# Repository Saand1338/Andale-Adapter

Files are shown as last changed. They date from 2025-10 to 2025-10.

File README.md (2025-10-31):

# Andale Adapter

The Andale Adapter Project is a Wii Remote–sized adapter for Wii Guitar Hero Controllers, powered by a Raspberry Pi Pico/Pico W running Santroller firmware.
This project, through the Santroller firmware, enables these controllers to function on PC/Xbox/PlayStation platforms through USB connectivity, or though Bluetooth via custom recievers also powered by a Raspberry Pi Pico W running Santroller firmware.
The circuit boards have been designed with hand assembly in mind, and requires the soldering of both through-hole components and surface mount devices (SMD). The use of SMD components makes a soldering plate recommended equipment, but sufficient pad clearence has been used to enable careful hand soldering.

---

## Repository Structure

This repository contains three main sections:

1. **Andale Adapter** - the Adapter itself, the "brains" of the project.
2. **Slim Receiver** - a compact Bluetooth receiver, designed for low height.
3. **Tiny Receiver** - a minimal volume Bluetooth receiver, designed for portability.

All three sections include:
- KiCAD project files and Gerber outputs.
- STL files for 3D printed enclosures.
- Autodesk Fusion project files for the STLs.
- Bills of Material (BOM) files in CSV format.

> **Note:** All enclosure STLs are designed for resin printing. Extensive use of overhangs makes them less ideal for FDM printing.

---

## Overview

The Andale Adapter is designed with certain optional elements. Depending on the desired configuration, builders can choose to integrate multiple additional features:

 Feature | Description |
----------|--------------|
 Bluetooth and/or USB connectivity | Supports both wireless and wired operation. |
 RGB LED support | Allows support for up to 10 RGB LEDs on customised PCBs though a USB Micro port. |
 Controller authentication support | Required for consoles that need controller verification, done so over a regular USB port. |
 AA battery power | Recommended for Bluetooth operation. Designed around NiMH rechargable batteries. |

> **Note:** For a Bluetooth setup USB Auth is not required on the adapter. It's only required for wired configuration on console systems that require it.

---

## Assembly Order

Due to the mixed component types and modular structure, the following rough build order is recommended:

1. Prepare customised components (e.g., modified headers, trimmed USB connectors).
2. Solder Surface Mount Devices (SMDs).
3. Solder USB connectors (if applicable).
4. Solder through-hole components (e.g., headers, battery terminals).
5. Solder add-in boards (Pico, Nunchuck adapter, accelerometer).
6. Final assembly into enclosures.

---

## Andale Adapter

The Andale Adapter is the primary focus of the project, and contains the most complex components.
A small internal cable can be made to route the Pico USB Micro to a USB-C breakout board, and a sample wiring diagram is included.
Due to height & space limitations, the PCBs in the adapter are 1mm thick by design.

### Adapter Components

| Component | Purpose |
|---|---|
| Mainboard | Core PCB carrying the Pico, accelerometer, and Nunchuck adapter. |
| Battery Board | Optional PCB for AA NiMH battery power and On/Off switch. |
| Connector Board | Optional PCB for controller authentication, RGB integration (with voltage boost). |
| Internal Cable | Adapting and routing the Pico USB Micro Port to a USB-C Port on the top of the case |

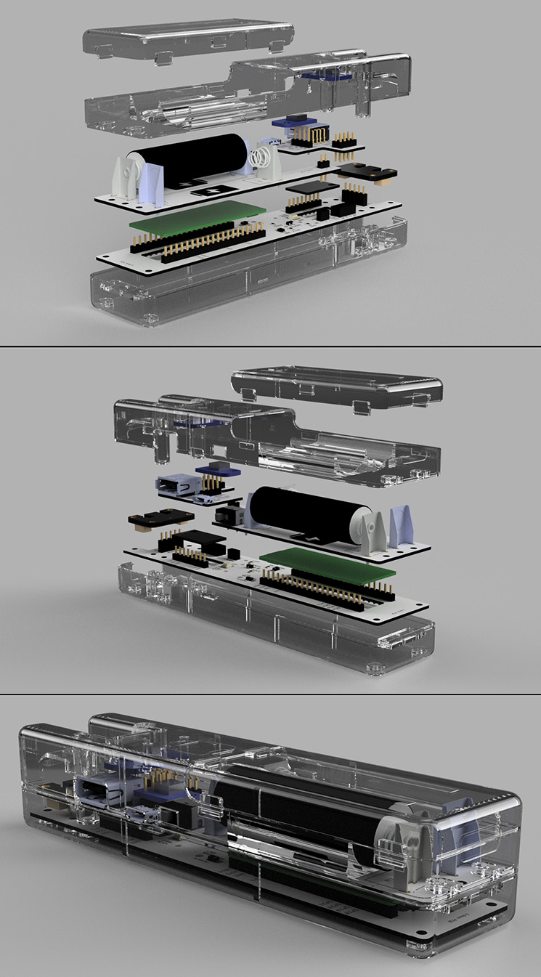
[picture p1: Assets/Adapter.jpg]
Adapter Render


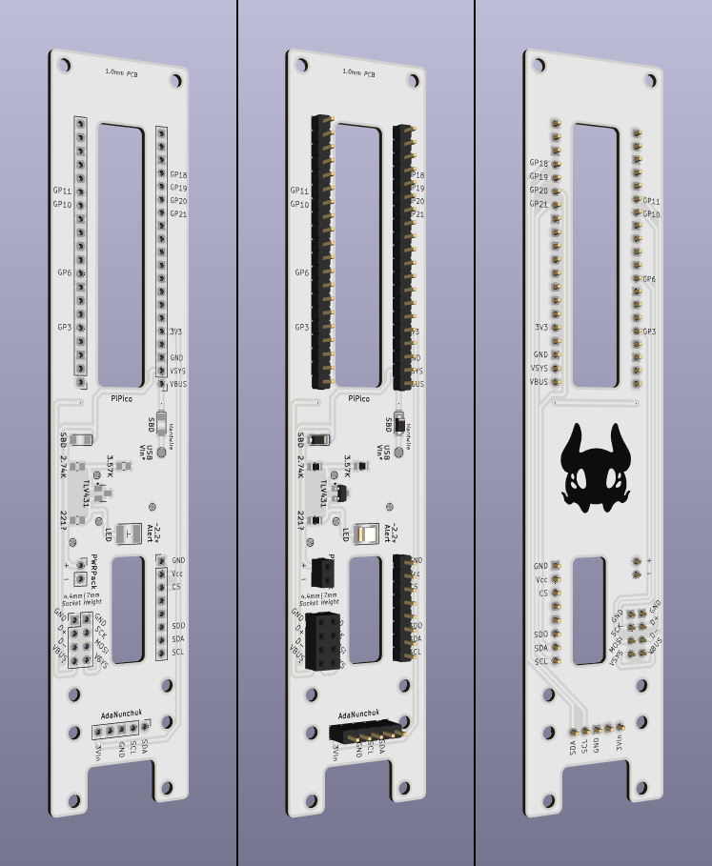
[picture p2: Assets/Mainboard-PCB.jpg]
Mainboard Render


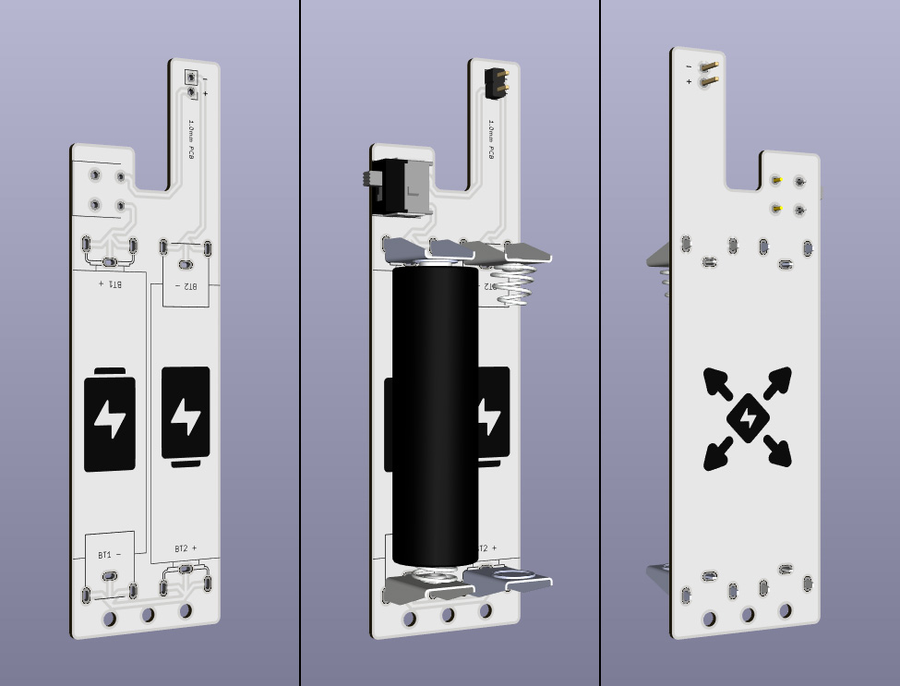
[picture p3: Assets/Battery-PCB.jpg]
Battery Board Render


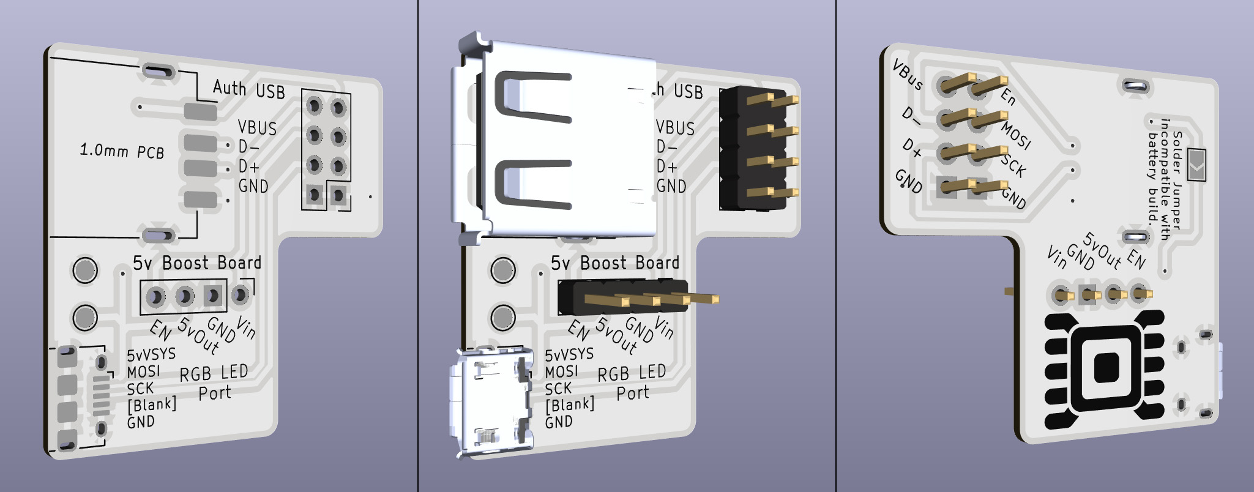
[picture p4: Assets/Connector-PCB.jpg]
Connector Board Render


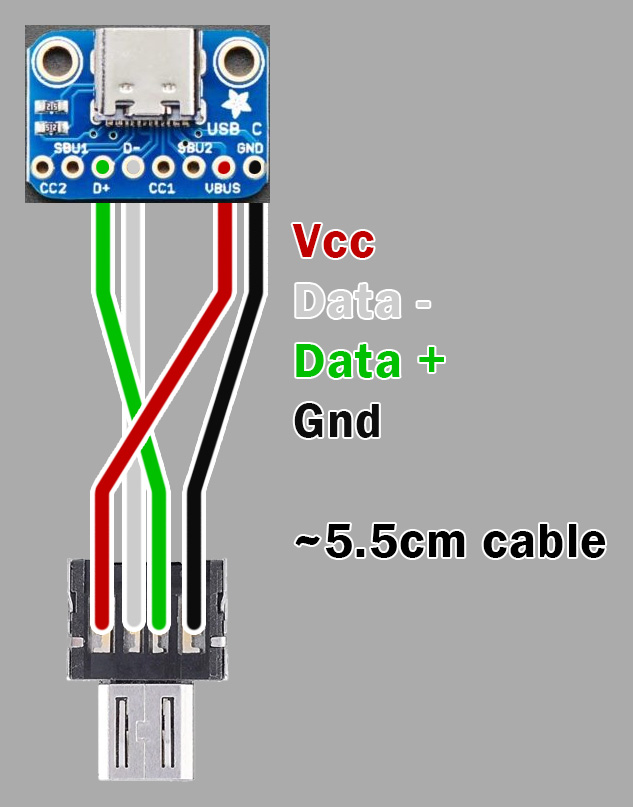
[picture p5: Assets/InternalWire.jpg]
Terrible Wiring Diagram


### Build Notes
- For Bluetooth setups, a Raspberry Pi Pico W is a requirement.
- For USB setups, either Pico or Pico W may be used.
- A USB cable or the USB-C breakout may be hardwired to the mainboard if preferred over using an internal USB Micro cable.

---

### Bill of Materials - Mainboard

| Part | Component Type | Part Code | Qty | Purpose | Notes |
|---|---|---|---|---|---|
| Pi Pico W | Commercial Product | - | 1 | Controller logic | Use Pico for wired-only builds. |
| 1x10 Low Profile Male Header | Through-hole | - | 2 | Mount for Pico W | - |
| 1x05 Male Header | Through-hole | - | 1 | Mount for Nunchuck Adapter | Requires double insulator height. |
| Adafruit Nunchuck Adapter | Commercial Product | - | 1 | Nunchuck connector integration | - |
| 1x08 Low Profile Male Header | Through-hole | - | 1 | Mount for ADXL345 | - |
| Triple Axis SEN0032 ADXL345 Board | Commercial Product | - | 1 | Accelerometer | Other ADXL345 board compatibility is uncertain. |
| 1x02 Low Profile Female Header | Through-hole | - | 1 | Powerboard plug | - |
| 1x04 Low Profile Female Header | Through-hole | - | 2 | Connector board plug | Insulator height 4 or 7 mm. |
| 20V 1A Schottky Diode | SMD (SOT-123F) | MBR120VLSFT1G | 1 | Power direction regulator | Required for battery or hardwired power. |
| LED | SMD (1208) | QBLP653-S5 | 1 | Low-voltage indicator | - |
| 1.25 V Voltage Shunt | SMD (DBZ) | TLV431DBZ | 1 | Voltage detection | Must use TL**V**431 variant. |
| 3.57 kΩ Resistor | SMD (0805) | RQ73C2A3K57BTD | 1 | Voltage divider | - |
| 2.74 kΩ Resistor | SMD (0805) | RQ73C2A2K74BTD | 1 | Voltage divider | - |
| 221 Ω Resistor | SMD (0805) | RQ73C2A221RBTD | 1 | LED current limiter | Value not optimal but functional. |
| USB Male to Micro Adapter | Commercial Product | - | 1 | Internal cable | Optional; unnecessary for a directly hardwired setup. |
| Adafruit USB-C Downstream Breakout | Commercial Product | - | 1 | External connector | - |
| Silicone Ribbon Cable (4× 28 AWG) | Commercial Product | - | 1 | Internal wiring | - |

---

### Bill of Materials - Battery Board

| Part | Component Type | Part Code | Qty | Purpose | Notes |
|---|---|---|---|---|---|
| 1x2 Male Header | Through-hole | - | 1 | Plug to mainboard | Mount upside down if using 7 mm tall header sockets. |
| On-Off Switch | Through-hole | AS11AH | 1 | Power control | - |
| AA Battery Terminal, Plate | Through-hole | Keystone 595 | 2 | Battery contact | - |
| AA Battery Terminal, Coil | Through-hole | Keystone 628 | 2 | Battery contact | - |

---

### Bill of Materials - Connector Board

| Part | Component Type | Part Code | Qty | Purpose | Notes |
|---|---|---|---|---|---|
| 1x04 Male Header | Through-hole | - | 2 | Plug to mainboard | Mount upside down if using 7 mm tall header sockets. |
| 1x04 Low Profile Male Header | Through-hole | - | 1 | Mount for TinyBoost | - |
| USB Micro Female | Through-hole | Amphenol 10118194-0001LF | 1 | RGB integration | Nonstandard use of USB port. |
| USB A Female | Through-hole | GCT USB1046 | 1 | Controller auth | Required for wired console use. |
| Adafruit MiniBoost 5V | Commercial Product | - | 1 | Voltage boost for RGB | Skip for non-battery builds. |

---

## Slim Receiver

The Slim Receiver is a Bluetooth receiver designed for consoles or PCs.
It uses a Pico W, connects directly via USB-A, and includes a secondary port for controller auth.

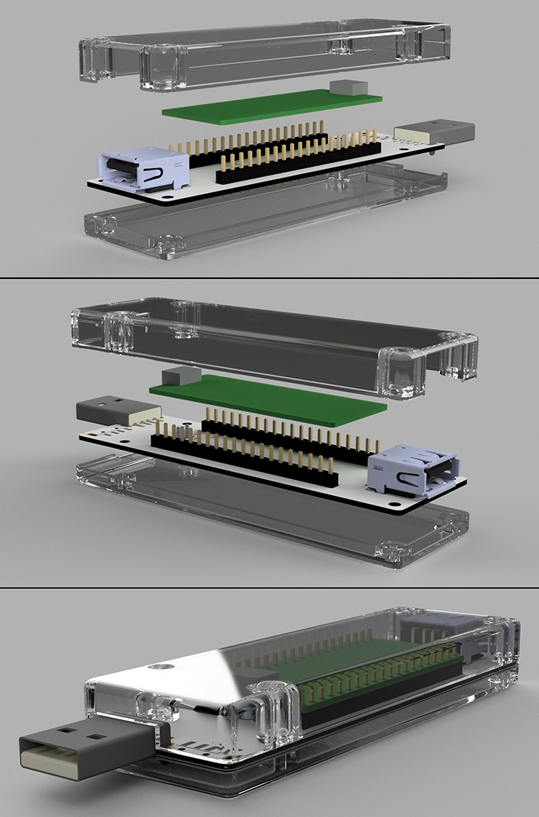
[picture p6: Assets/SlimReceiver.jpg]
Slim Receiver Render


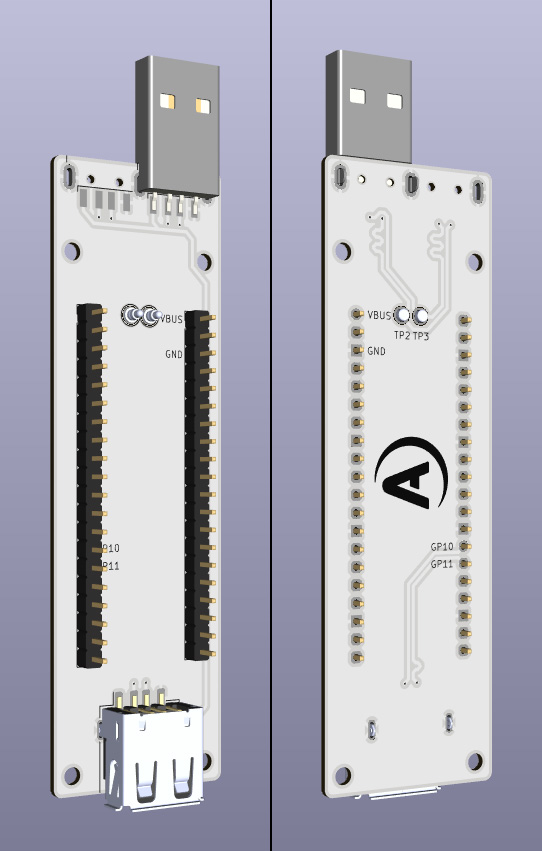
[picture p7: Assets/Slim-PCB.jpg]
Slim Board Render


### Key Characteristics
- Compact vertical height.
- Left- or right-offset USB configuration so two recievers can be used side-by-side

### Bill of Materials - Slim Receiver

| Part | Component Type | Part Code | Qty | Purpose | Notes |
|---|---|---|---|---|---|
| Pi Pico W | Commercial Product | - | 1 | Logic | Required. |
| 1x10 Low Profile Male Header | Through-hole | - | 2 | Mount for Pico W | - |
| USB A Male | Through-hole | CNCTech 1001-011-01101 | 1 | Plug for console/PC | Offset configuration possible. |
| USB A Female | Through-hole | GCT USB1046 | 1 | Auth plug | Required for consoles needing authentication. |
| 3.18 mm → 1.78 mm Pogo Pin | Through-hole | 0926-1-15-20-75-14-11-0 | 2 | Pico testpoint connection | 2.54 mm target height. |

---

## Tiny Receiver

The Tiny Receiver alternatively offers a minimal design for ease of transport. It does however have a larger vertical height and worse horizontal clearance, so fitting multiple in side-by-side USB ports may be impossible.
It mounts the Pico W directly underneath the PCB, requiring precise soldering and a fine-tipped soldering iron.

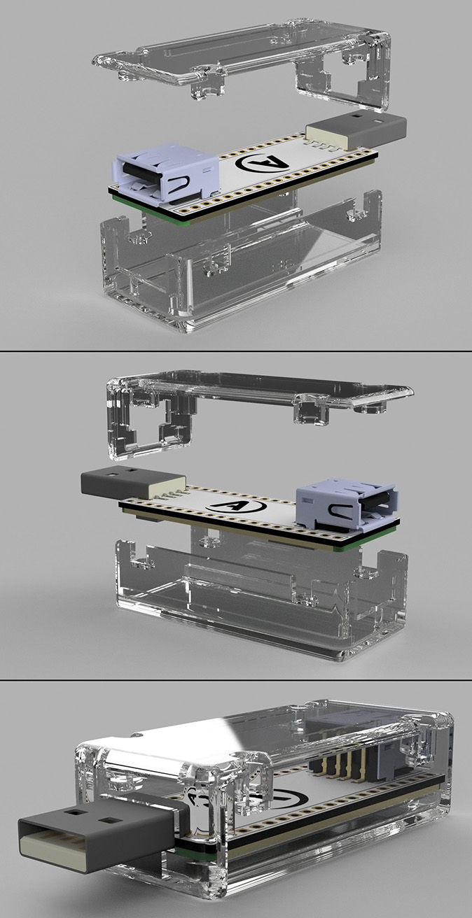
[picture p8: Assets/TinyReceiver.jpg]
Tiny Receiver Render


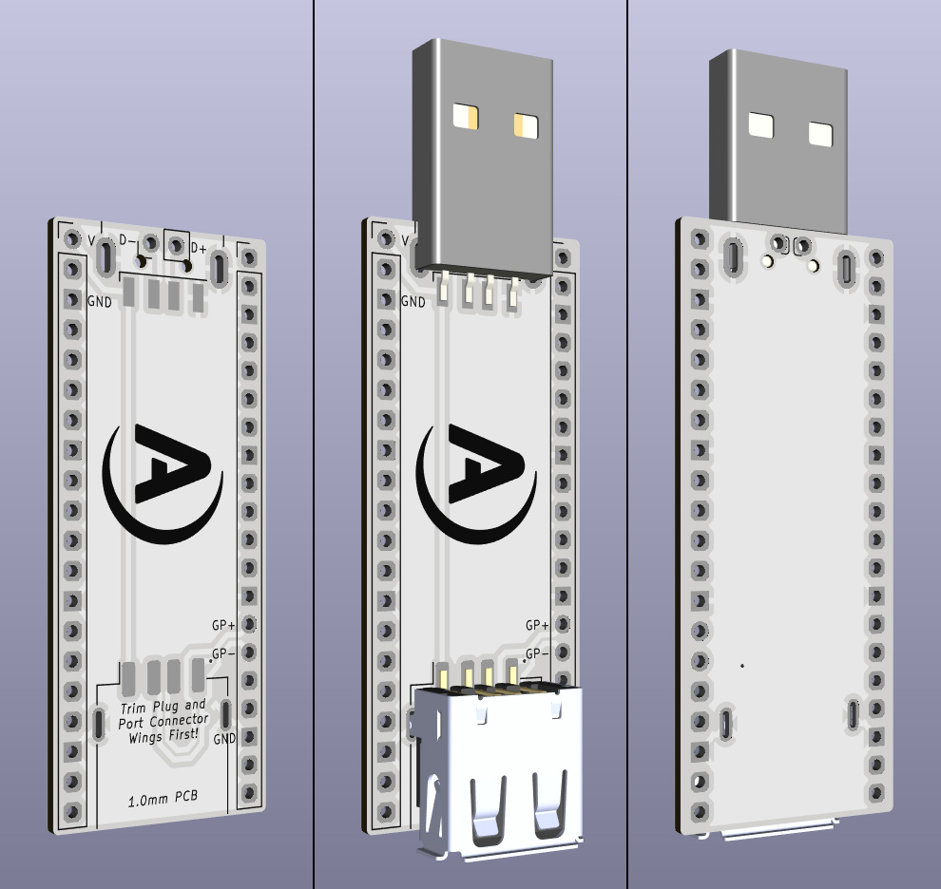
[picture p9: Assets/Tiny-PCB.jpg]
Tiny Board Render


### Build Notes
- Mount the Pico W on the underside and solder through the seven marked pads.
- Trim USB plug and port wings to fit enclosure.
- Difficult to build & repair. Not recommended.

### Bill of Materials - Tiny Receiver

| Part | Component Type | Part Code | Qty | Purpose | Notes |
|---|---|---|---|---|---|
| Pi Pico W | Commercial Product | - | 1 | Logic | Mounted underside. |
| USB A Male | Through-hole | CNCTech 1001-011-01101 | 1 | Main plug | Trim wings to < 1 mm. |
| USB A Female | Through-hole | GCT USB1046 | 1 | Auth port | Trim wings to < 1 mm. |

---

## Hardware Fasteners

A bulk pack of metric M2 machine screws is recommended.

| Section | Part | Component Type | Qty | Purpose |
|---|---|---|---|---|
| Adapter Shell | M2 Machine Screw 4 mm | Commercial Product | 3 | Mounts mainboard, power board |
| Adapter Shell | M2 Machine Screw 6 mm | Commercial Product | 4 | Mounts breakout, shell rear |
| Adapter Shell | M2 Machine Screw 8 mm | Commercial Product | 2 | Mounts shell front |
| Slim Shell | M2 Machine Screw 6 mm | Commercial Product | 4 | Holds halves together |
| Tiny Shell | M2 Machine Screw 6 mm | Commercial Product | 4 | Holds halves together |

---

## Firmware

This project uses Santroller firmware by sanjay900.
All credit for firmware functionality belongs to the original author.

For more information visit the Santroller website.

---

## Thanks

Thank you to Sanjay & the Santroller community. They were openly welcoming and provided a great deal of support and validation during the development of this project. It would not have been possible without them.

---

## Licensing

All designs, documents, and files in this repository are released under the **Creative Commons Attribution–ShareAlike (CC-BY-SA)** license.
You are free to modify, distribute, and remix, provided that proper credit is given and derivatives are shared under the same terms.

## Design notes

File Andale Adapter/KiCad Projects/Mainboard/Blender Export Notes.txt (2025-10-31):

Blender Export Notes

Using Blender to convert board WRLs to OBJ for import into Fusion 360, on my system the axies need to be set to positive z and positive y to then import in the expected planar orientation.

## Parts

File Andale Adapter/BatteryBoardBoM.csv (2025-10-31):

Part | Component Type | Part Code | Qty | Purpose | Notes
1x2 Male Header | Through-hole |  | 1 | Plug into Mainboard | For 7mm header insulator mount upside down
On-Off Switch | Through-hole | AS11AH | 1 | Power switch
AA Battery Terminal, Plate | Through-hole | 595 | 2 | Battery mount (plate)
AA Battery Terminal, Coil | Through-hole | 628 | 2 | Battery mount (coil)

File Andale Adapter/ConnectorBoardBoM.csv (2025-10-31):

Part | Component Type | Part Code | Qty | Purpose | Notes
1x04 Male Header | Through-hole |  | 2 | Plug into Mainboard | For 7mm insulator mount upside down
1x04 Low Profile Male Header | Through-hole |  | 1 | Mount for TinyBoost
USB Micro Female | Through-hole | Amphenol 10118194-0001LF | 1 | RGB integration (abuse of USB Micro)
USB A Female | Through-hole | GCT USB1046 | 1 | Controller auth (Wired)
Adafruit MiniBoost 5V | Commercial Product |  | 1 | Boost converter for RGB on battery | Optional for non-battery builds

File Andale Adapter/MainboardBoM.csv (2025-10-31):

Part | Component Type | Part Code | Qty | Purpose | Notes
Pi Pico W | Commercial Product |  | 1 | Brains | Use Pico W for Bluetooth builds
1x10 Low Profile Male Header (x2) | Through-hole |  | 2 | Mount for Pico W
1x05 Male Header | Through-hole |  | 1 | Mount for Nunchuck Adapter | Requires double insulator height; custom modification
Adafruit Nunchuck Adapter | Commercial Product |  | 1 | Nunchuck connector integration
1x08 Low Profile Male Header | Through-hole |  | 1 | Mount for ADXL345
Triple Axis SEN0032 ADXL345 Board | Commercial Product |  | 1 | Accelerometer | Other ADXL345 compatibility unverified
1x02 Low Profile Female Header | Through-hole |  | 1 | Powerboard plug
1x04 Low Profile Female Header (x2) | Through-hole |  | 2 | Connector board plug | Insulator height must be 4mm or 7mm
20V 1A Schottky Diode | SMD (SOT-123F) | MBR120VLSFT1G | 0-1 | Power direction regulator | Required for battery or hardwired power
LED | SMD (1208) | QBLP653-S5 | 1 | Low-voltage indicator
1.25 V Voltage Shunt | SMD (DBZ) | TLV431DBZ | 1 | Voltage detection | Must use TLV variant (not TL431)
3.57 kΩ Resistor | SMD (0805) | RQ73C2A3K57BTD | 1 | Voltage divider
2.74 kΩ Resistor | SMD (0805) | RQ73C2A2K74BTD | 1 | Voltage divider
221 Ω Resistor | SMD (0805) | RQ73C2A221RBTD | 1 | LED current limiter | Value arbitrary; not optimized
USB Male to USB-Micro Male adapter | Commercial Product |  | 1 | Internal cable (optional) | Unnecessary in hardwire config
Adafruit USB C Downstream Breakout | Commercial Product |  | 1 | USB-C connector breakout
Silicone Ribbon Cable, 4x 28AWG | Commercial Product |  | 1 | Internal wiring

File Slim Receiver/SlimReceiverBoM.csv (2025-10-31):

Part | Component Type | Part Code | Qty | Purpose | Notes
Pi Pico W | Commercial Product |  | 1 | Brains
1x10 Low Profile Male Header (x2) | Through-hole |  | 2 | Mount for Pico W
USB A Male | Through-hole | CNCTech 1001-011-01101 | 1 | USB stick plug | Offset left/right configs available
USB A Female | Through-hole | GCT USB1046 | 1 | Auth plug (wireless config)
3.18mm->1.78mm Pogo Pin | Through-hole | 0926-1-15-20-75-14-11-0 | 2 | Pico testpoint connectors | Target height 2.54mm (header insulator height)

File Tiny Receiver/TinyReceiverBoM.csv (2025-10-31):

Part | Component Type | Part Code | Qty | Purpose | Notes
Pi Pico W | Commercial Product |  | 1 | Brains | Mounted underside; advanced soldering required
USB A Male | Through-hole | CNCTech 1001-011-01101 | 1 | USB stick plug | Trim mounting prongs under 1mm
USB A Female | Through-hole | GCT USB1046 | 1 | Auth plug | Trim mounting prongs under 1mm

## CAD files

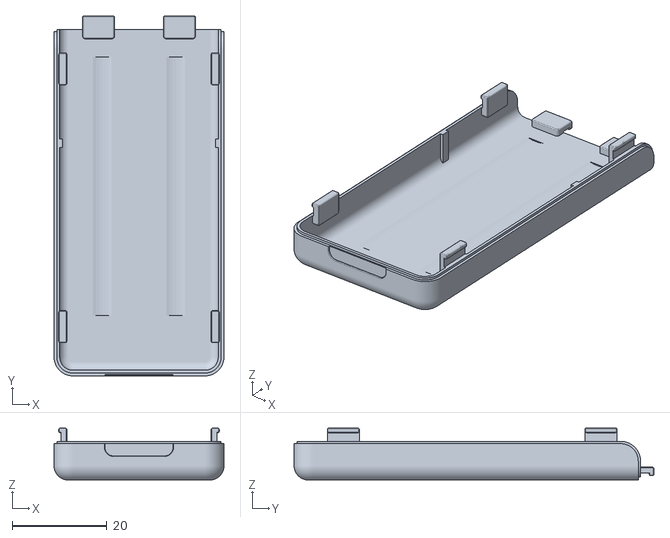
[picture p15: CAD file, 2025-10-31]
Andale Adapter/Fusion360 Project/STL Exports/AdapterShellBatteryCover.stl
35.8 x 75.8 x 10.9

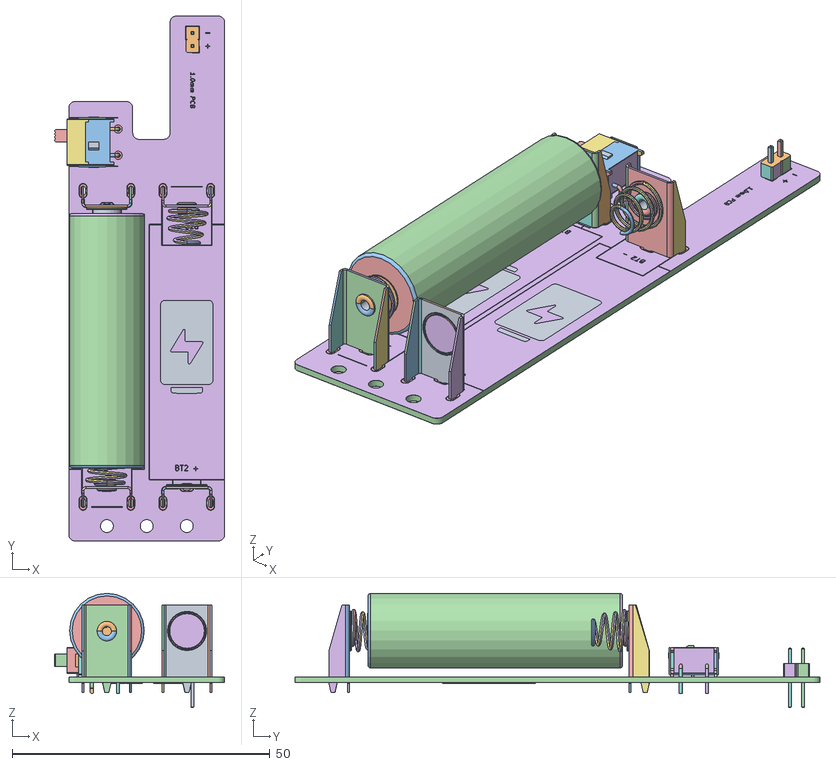
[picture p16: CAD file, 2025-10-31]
Andale Adapter/KiCad Projects/Exports/BatteryBoard.obj
33.1 x 101.9 x 22.2
SHAPE_1_IndexedFaceSet
SHAPE_2_IndexedFaceSet
SHAPE_3_IndexedFaceSet
SHAPE_4_IndexedFaceSet
SHAPE_5_IndexedFaceSet
SHAPE_6_IndexedFaceSet
SHAPE_7_IndexedFaceSet
SHAPE_8_IndexedFaceSet
SHAPE_9_IndexedFaceSet
SHAPE_10_IndexedFaceSet
SHAPE_11_IndexedFaceSet
SHAPE_12_IndexedFaceSet
SHAPE_13_IndexedFaceSet
SHAPE_14_IndexedFaceSet
SHAPE_15_IndexedFaceSet
SHAPE_16_IndexedFaceSet
SHAPE_17_IndexedFaceSet
SHAPE_18_IndexedFaceSet
SHAPE_19_IndexedFaceSet
SHAPE_20_IndexedFaceSet
SHAPE_21_IndexedFaceSet
SHAPE_22_IndexedFaceSet
SHAPE_23_IndexedFaceSet
SHAPE_24_IndexedFaceSet
SHAPE_25_IndexedFaceSet
SHAPE_26_IndexedFaceSet
SHAPE_27_IndexedFaceSet
SHAPE_28_IndexedFaceSet
SHAPE_29_IndexedFaceSet
SHAPE_30_IndexedFaceSet
SHAPE_31_IndexedFaceSet
SHAPE_32_IndexedFaceSet
SHAPE_33_IndexedFaceSet
SHAPE_34_IndexedFaceSet
SHAPE_35_IndexedFaceSet
SHAPE_36_IndexedFaceSet
SHAPE_37_IndexedFaceSet
SHAPE_38_IndexedFaceSet
SHAPE_39_IndexedFaceSet
SHAPE_40_IndexedFaceSet
SHAPE_41_IndexedFaceSet
SHAPE_42_IndexedFaceSet
SHAPE_43_IndexedFaceSet
SHAPE_44_IndexedFaceSet
SHAPE_45_IndexedFaceSet
SHAPE_46_IndexedFaceSet
SHAPE_47_IndexedFaceSet
SHAPE_48_IndexedFaceSet
SHAPE_49_IndexedFaceSet
SHAPE_50_IndexedFaceSet
SHAPE_51_IndexedFaceSet
SHAPE_52_IndexedFaceSet
SHAPE_53_IndexedFaceSet
SHAPE_54_IndexedFaceSet
SHAPE_55_IndexedFaceSet
SHAPE_56_IndexedFaceSet
SHAPE_1_IndexedFaceSet.001
SHAPE_2_IndexedFaceSet.001
SHAPE_3_IndexedFaceSet.001
SHAPE_4_IndexedFaceSet.001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

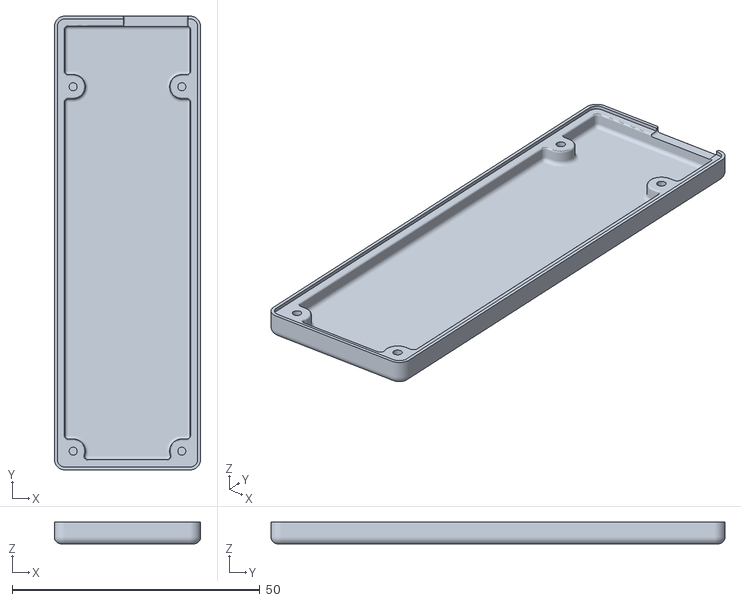
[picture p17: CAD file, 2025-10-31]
Slim Receiver/Fusion360 Project/STL Exports/SlimRight_Bottom.stl
29.5 x 91.6 x 4.41

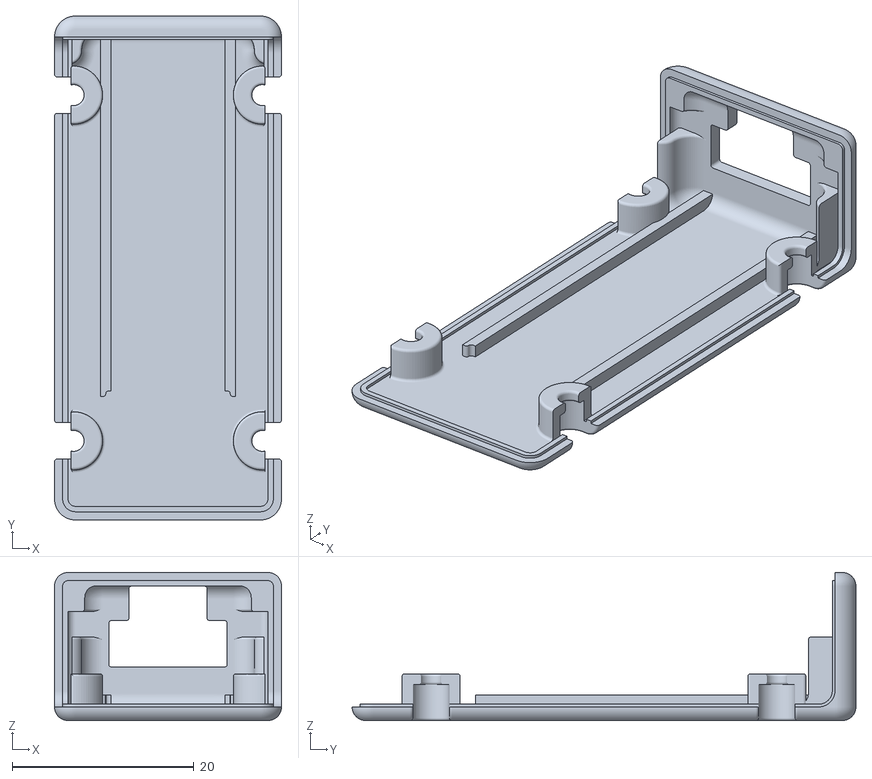
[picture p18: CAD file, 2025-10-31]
Tiny Receiver/Fusion360 Project/STL Exports/Shell_Top.stl
25.0 x 55.5 x 16.3

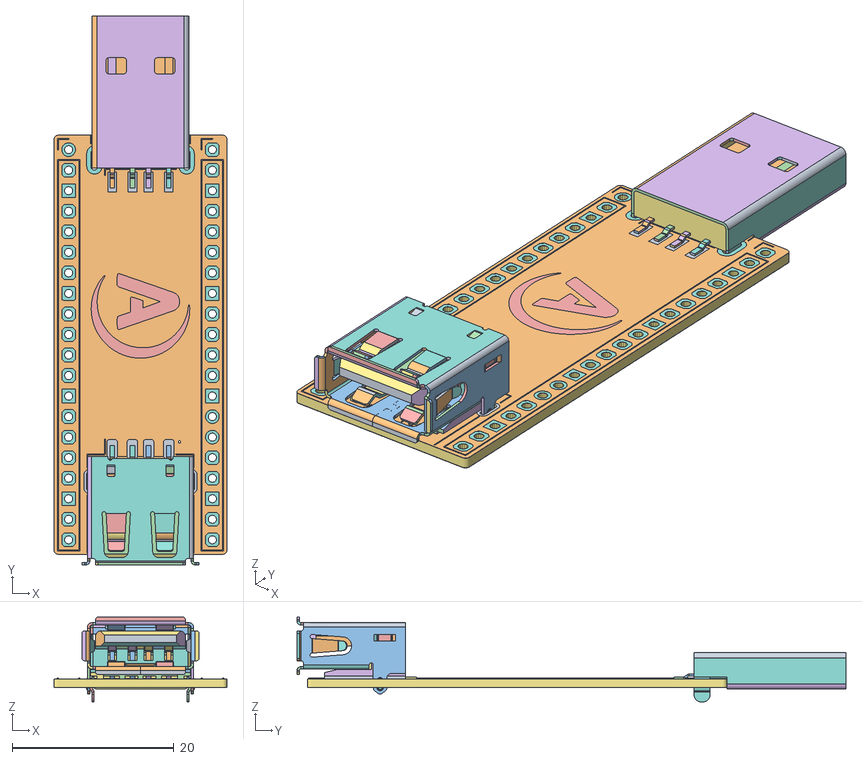
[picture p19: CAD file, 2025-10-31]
Tiny Receiver/KiCad Project/Exports/TinyReceiver.obj
21.4 x 67.9 x 10.5
SHAPE_1_IndexedFaceSet
SHAPE_2_IndexedFaceSet
SHAPE_3_IndexedFaceSet
SHAPE_4_IndexedFaceSet
SHAPE_5_IndexedFaceSet
SHAPE_6_IndexedFaceSet
SHAPE_7_IndexedFaceSet
SHAPE_8_IndexedFaceSet
SHAPE_9_IndexedFaceSet
SHAPE_10_IndexedFaceSet
SHAPE_11_IndexedFaceSet
SHAPE_12_IndexedFaceSet
SHAPE_13_IndexedFaceSet
SHAPE_14_IndexedFaceSet
SHAPE_15_IndexedFaceSet
SHAPE_16_IndexedFaceSet
SHAPE_17_IndexedFaceSet
SHAPE_18_IndexedFaceSet
SHAPE_19_IndexedFaceSet
SHAPE_20_IndexedFaceSet
SHAPE_21_IndexedFaceSet
SHAPE_22_IndexedFaceSet
SHAPE_23_IndexedFaceSet
SHAPE_24_IndexedFaceSet
SHAPE_25_IndexedFaceSet
SHAPE_26_IndexedFaceSet
SHAPE_27_IndexedFaceSet
SHAPE_28_IndexedFaceSet
SHAPE_29_IndexedFaceSet
SHAPE_30_IndexedFaceSet
SHAPE_31_IndexedFaceSet
SHAPE_32_IndexedFaceSet
SHAPE_33_IndexedFaceSet
SHAPE_34_IndexedFaceSet
SHAPE_35_IndexedFaceSet
SHAPE_36_IndexedFaceSet
SHAPE_37_IndexedFaceSet
SHAPE_38_IndexedFaceSet
SHAPE_39_IndexedFaceSet
SHAPE_40_IndexedFaceSet
SHAPE_41_IndexedFaceSet
SHAPE_42_IndexedFaceSet
SHAPE_43_IndexedFaceSet
SHAPE_44_IndexedFaceSet
SHAPE_45_IndexedFaceSet
SHAPE_46_IndexedFaceSet
SHAPE_47_IndexedFaceSet
SHAPE_48_IndexedFaceSet
SHAPE_49_IndexedFaceSet
SHAPE_50_IndexedFaceSet
SHAPE_51_IndexedFaceSet
SHAPE_52_IndexedFaceSet
SHAPE_53_IndexedFaceSet
SHAPE_54_IndexedFaceSet
SHAPE_55_IndexedFaceSet
SHAPE_56_IndexedFaceSet
SHAPE_57_IndexedFaceSet
SHAPE_58_IndexedFaceSet
SHAPE_59_IndexedFaceSet
SHAPE_60_IndexedFaceSet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

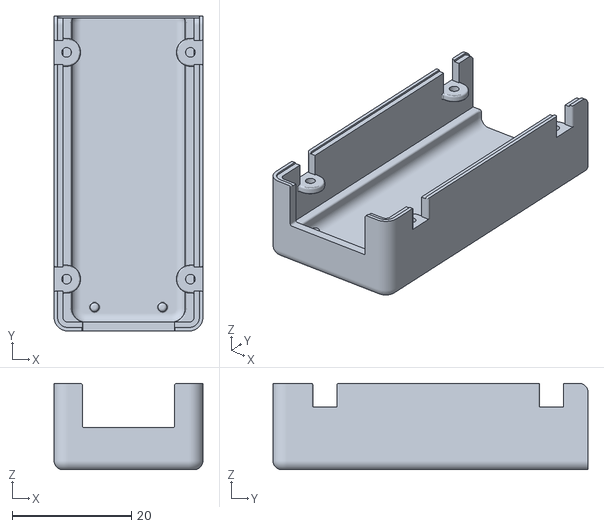
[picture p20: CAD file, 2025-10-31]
Tiny Receiver/Fusion360 Project/STL Exports/Shell_Bottom.stl
25.0 x 52.9 x 14.5

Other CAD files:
Slim Receiver/Fusion360 Project/STL Exports/SlimLeft_Bottom.stl
Andale Adapter/Fusion360 Project/AndaleAdapter.f3d
Slim Receiver/Fusion360 Project/SlimReceiver.f3d
Tiny Receiver/Fusion360 Project/TinyReceiver.f3d

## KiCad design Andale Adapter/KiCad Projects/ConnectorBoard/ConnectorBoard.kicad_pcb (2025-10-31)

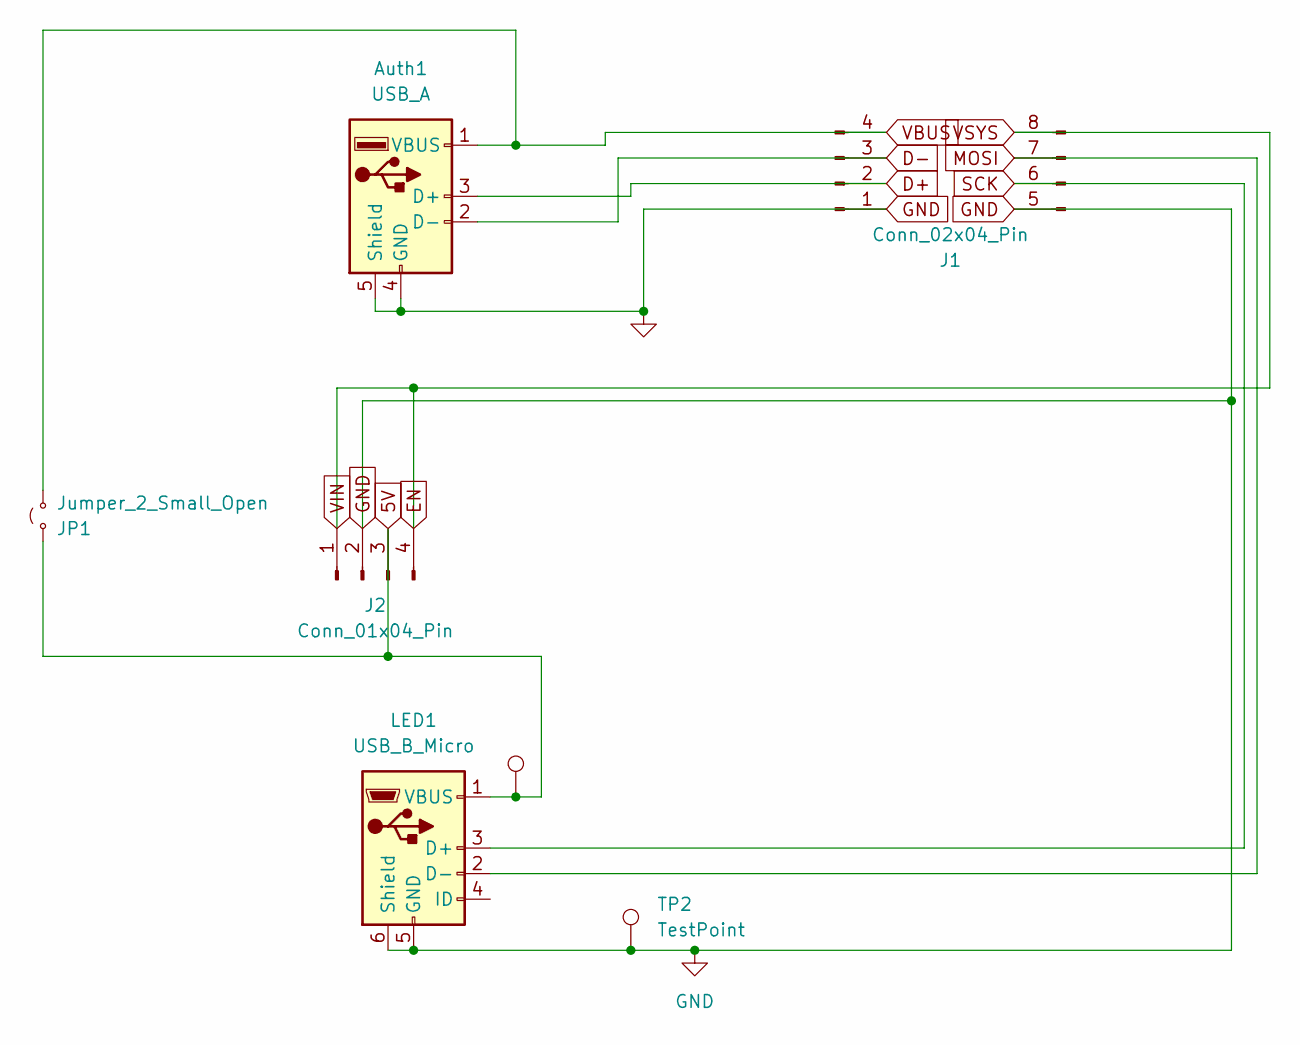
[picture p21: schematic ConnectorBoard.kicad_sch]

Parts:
Auth1: USB_A; USB_A_Receptacle_GCT_USB1046_Model
J1: Conn_02x04_Pin; PinHeader_2x04_P2.54mm_Vertical_Inverted
J2: Conn_01x04_Pin; PinHeader_1x04_P2.54mm_Vertical
JP1: Jumper_2_Small_Open; SolderJumper-2_P1.3mm_Open_TrianglePad1.0x1.5mm
LED1: USB_B_Micro; USB_Micro-B_Amphenol_10118194-0001LF_Horizontal_Model
TP1, TP2: TestPoint; TestPoint_Pad_D1.5mm

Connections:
5V: J2.3, JP1.2 (B), LED1.1 (VBUS), TP1.1
D+: Auth1.3 (D+), J1.2
D-: Auth1.2 (D-), J1.3
EN: J1.8, J2.1, J2.4
GND: Auth1.4 (GND), Auth1.5 (Shield), J1.1, J1.5, J2.2, LED1.5 (GND), LED1.6 (Shield), TP2.1
MOSI: J1.7, LED1.2 (D-)
SCK: J1.6, LED1.3 (D+)
VBUS: Auth1.1 (VBUS), J1.4, JP1.1 (A)

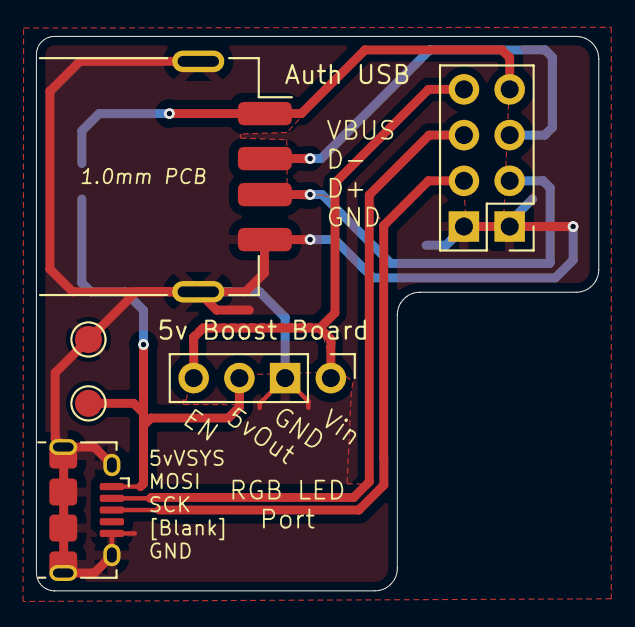
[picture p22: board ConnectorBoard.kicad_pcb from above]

Board: 2 copper layers, 31.2 x 30.8 mm, 7 parts (1 on the bottom side), 8 nets.

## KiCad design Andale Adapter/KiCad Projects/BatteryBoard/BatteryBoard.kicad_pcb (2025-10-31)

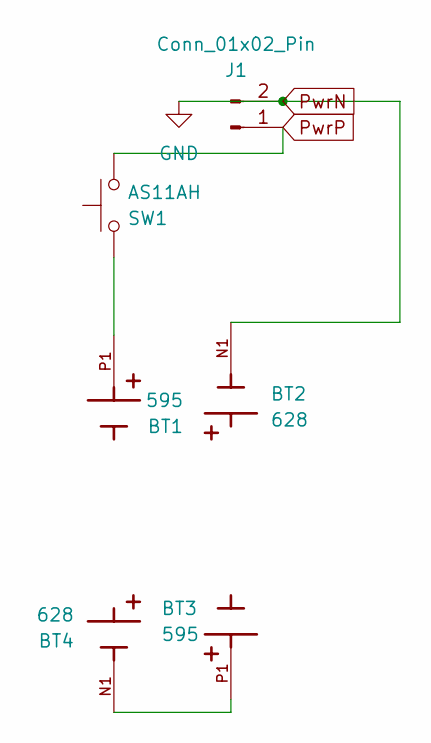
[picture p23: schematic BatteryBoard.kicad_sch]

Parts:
BT1: 595; BAT_595; PARTREV E
BT2, BT4: 628; BAT_628; PARTREV A
BT3: 595; BAT_595_NoBatt; PARTREV E
J1: Conn_01x02_Pin; PinHeader_1x02_P2.54mm_Vertical-Inverted
SW1: AS11AH

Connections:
unnamed: BT1.P1, SW1.2
unnamed: BT3.P1, BT4.N1
PwrN: BT2.N1, J1.2
PwrP: J1.1, SW1.1

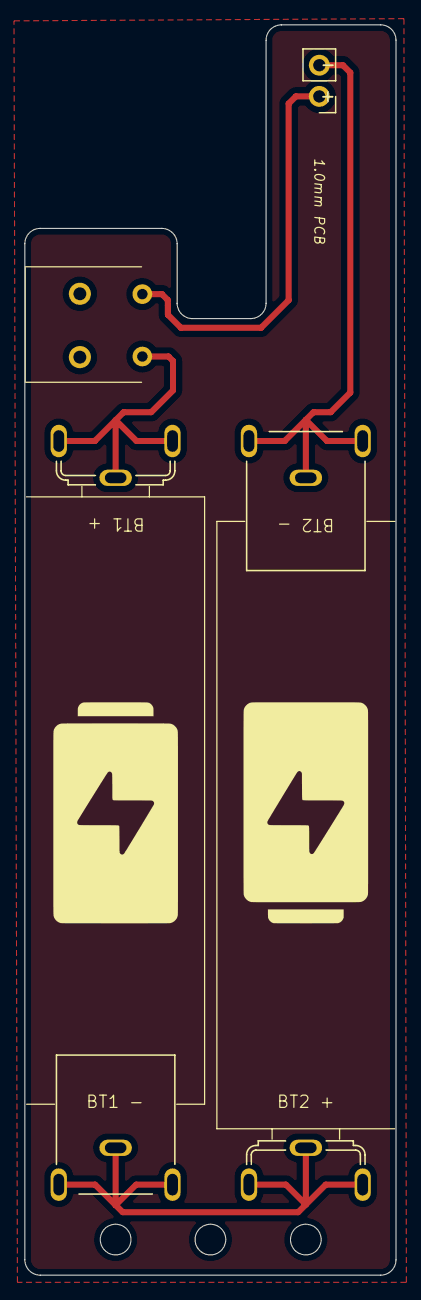
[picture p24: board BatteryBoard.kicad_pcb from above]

Board: 2 copper layers, 30.2 x 101.9 mm, 6 parts (0 on the bottom side), 4 nets.

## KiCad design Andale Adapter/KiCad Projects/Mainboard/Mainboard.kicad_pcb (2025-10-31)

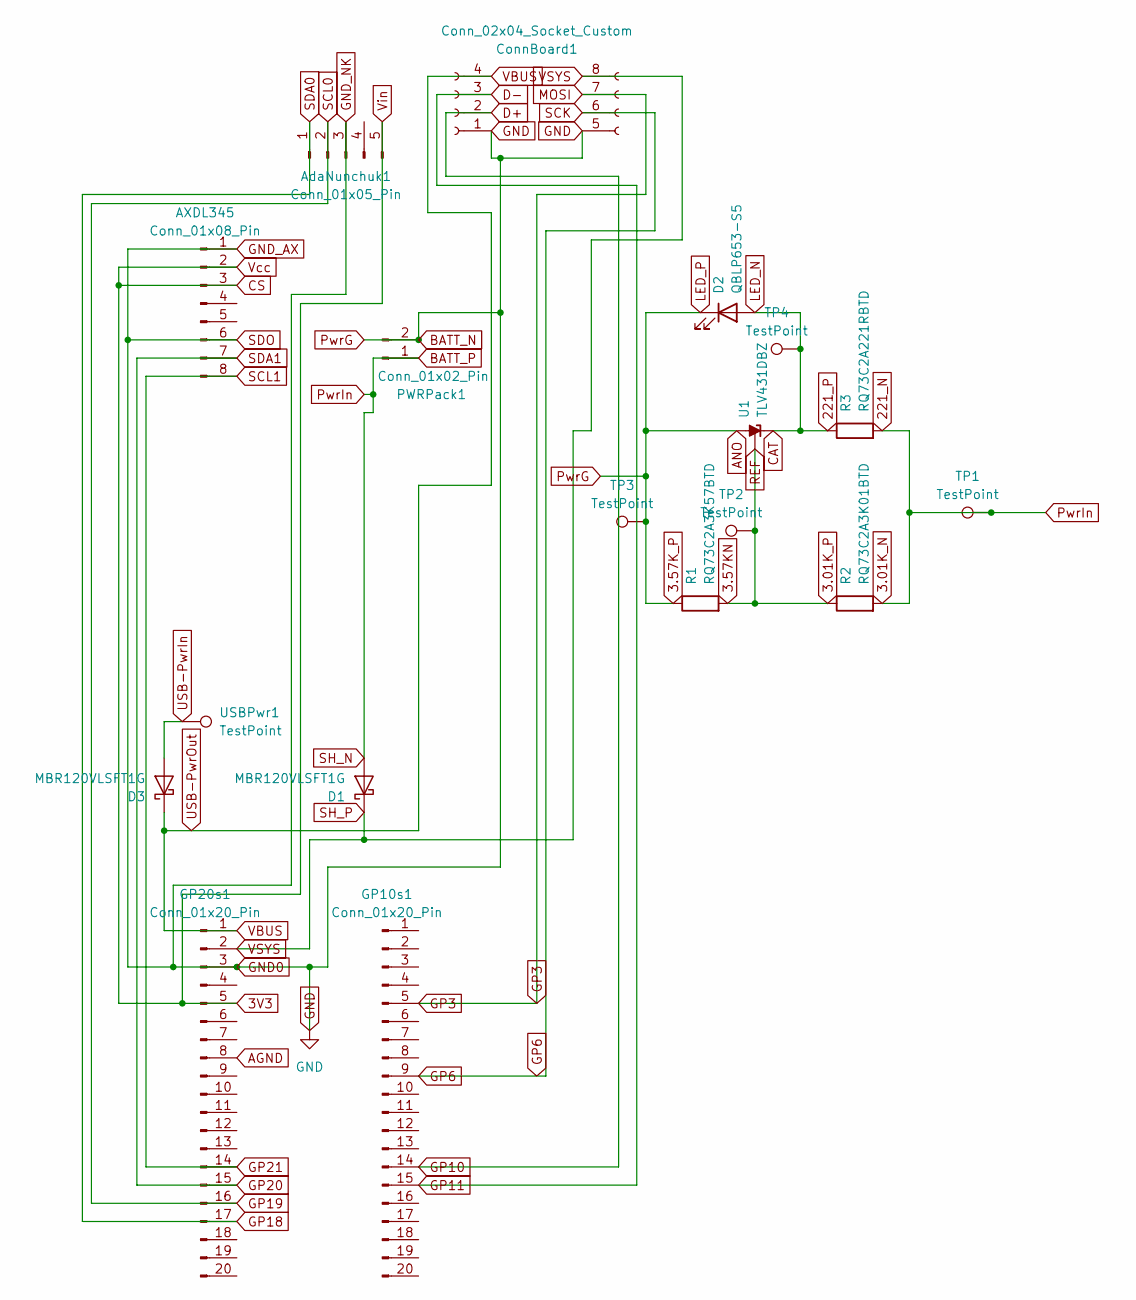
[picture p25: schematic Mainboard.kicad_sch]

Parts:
AXDL345: Conn_01x08_Pin; PinHeader_1x08_P2.54mm_Vertical-LowProfile
AdaNunchuk1: Conn_01x05_Pin; PinHeader_1x05_P2.54mm_Vertical-DoubleInsulator
ConnBoard1: Conn_02x04_Socket_Custom; PinSocket_2x04_P2.54mm_Vertical-4mm_Mirrored
D1, D3: MBR120VLSFT1G; D_SOD-123F-HandSoldering-0.25mm
D2: QBLP653-S5; LED_1208_Metric_Pad2.4x3.20mm_HandSolder
GP10s1, GP20s1: Conn_01x20_Pin; PinHeader_1x20_P2.54mm_Vertical-LowProfile
PWRPack1: Conn_01x02_Pin; PinSocket_1x02_P2.54mm_Vertical-4mm
R1: RQ73C2A3K57BTD; R_0805_2012Metric_Pad1.20x1.40mm_HandSolder
R2: RQ73C2A3K01BTD; R_0805_2012Metric_Pad1.20x1.40mm_HandSolder
R3: RQ73C2A221RBTD; R_0805_2012Metric_Pad1.20x1.40mm_HandSolder
TP1, TP2, TP3, TP4: TestPoint; TestPoint_Pad_D1.0mm
U1: TLV431DBZ; SOT-23-HandSoldering-0.25mm
USBPwr1: TestPoint; TestPoint_Pad_D1.5mm

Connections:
3.01K_P: R1.2, R2.1, TP2.1, U1.1 (REF)
3V3: AXDL345.2, AXDL345.3, AdaNunchuk1.5, GP20s1.5
221_N: D1.2 (A), PWRPack1.1, R2.2, R3.2, TP1.1
221_P: D2.2 (A), R3.1, TP4.1, U1.2 (K)
AGND: GP20s1.8
D+: ConnBoard1.2, GP10s1.14
D-: ConnBoard1.3, GP10s1.15
GND: AXDL345.1, AXDL345.6, AdaNunchuk1.3, ConnBoard1.1, ConnBoard1.5, D2.1 (K), GP10s1.3, GP10s1.8, GP10s1.13, GP10s1.18, GP20s1.3, GP20s1.13, GP20s1.18, PWRPack1.2, R1.1, TP3.1, U1.3 (A)
GP3: ConnBoard1.7, GP10s1.5
GP6: ConnBoard1.6, GP10s1.9
GP18: AdaNunchuk1.1, GP20s1.17
GP19: AdaNunchuk1.2, GP20s1.16
GP20: AXDL345.7, GP20s1.15
GP21: AXDL345.8, GP20s1.14
SH_P: ConnBoard1.8, D1.1 (K), GP20s1.2
USB-PwrIn: D3.2 (A), USBPwr1.1
USB-PwrOut: ConnBoard1.4, D3.1 (K), GP20s1.1

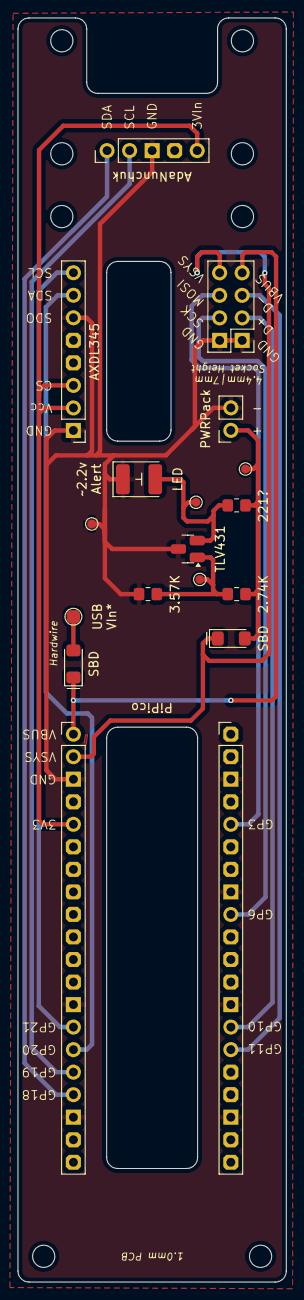
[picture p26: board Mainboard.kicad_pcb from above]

Board: 2 copper layers, 30.2 x 142.5 mm, 18 parts (0 on the bottom side), 16 nets.

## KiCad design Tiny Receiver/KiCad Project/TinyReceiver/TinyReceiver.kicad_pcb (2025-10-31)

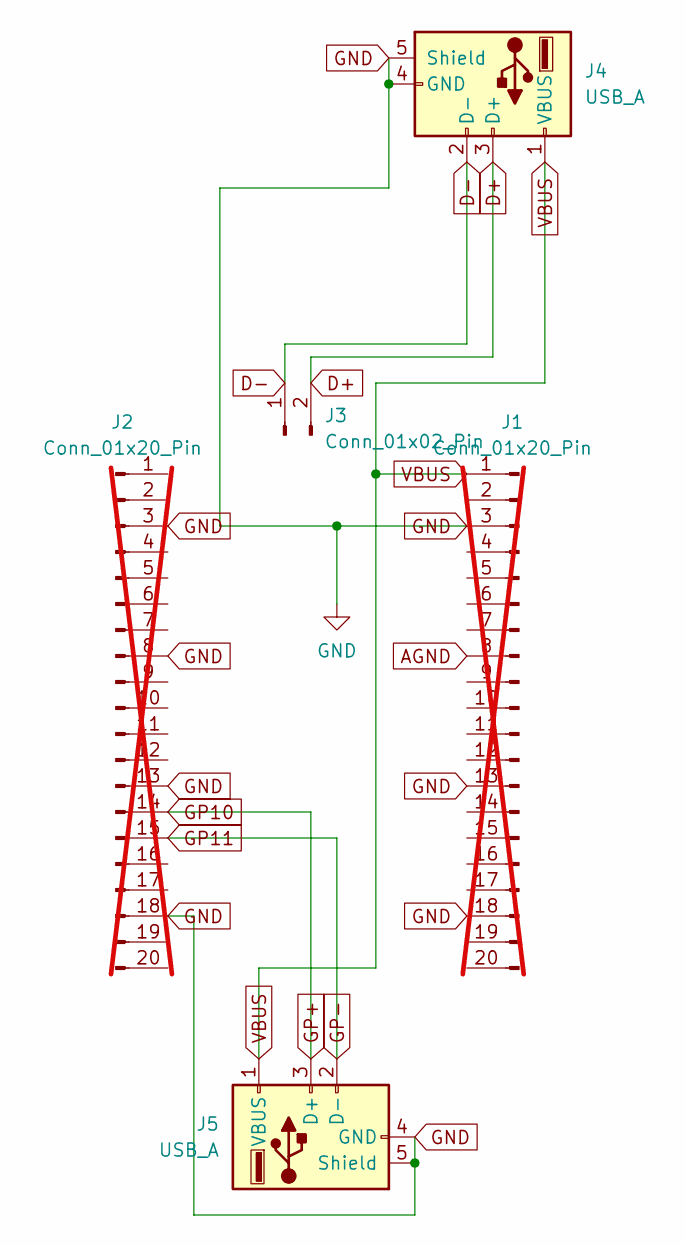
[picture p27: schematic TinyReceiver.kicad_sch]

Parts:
J1, J2: Conn_01x20_Pin; PinHeader_1x20_P2.54mm_Vertical_Low_Profile; not fitted
J3: Conn_01x02_Pin; PinHeader_1x02_P2.54mm_Vertical
J4: USB_A; USB_A_CNCTech_1001-011-01101_Horizontal
J5: USB_A; USB_A_Receptacle_GCT_USB1046_Model

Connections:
AGND: J1.8
D+: J3.2, J4.3 (D+)
D-: J3.1, J4.2 (D-)
GND: J1.3, J1.13, J1.18, J2.3, J2.8, J2.13, J2.18, J4.4 (GND), J4.5 (Shield), J5.4 (GND), J5.5 (Shield)
GP+: J2.14, J5.3 (D+)
GP-: J2.15, J5.2 (D-)
VBUS: J1.1, J4.1 (VBUS), J5.1 (VBUS)

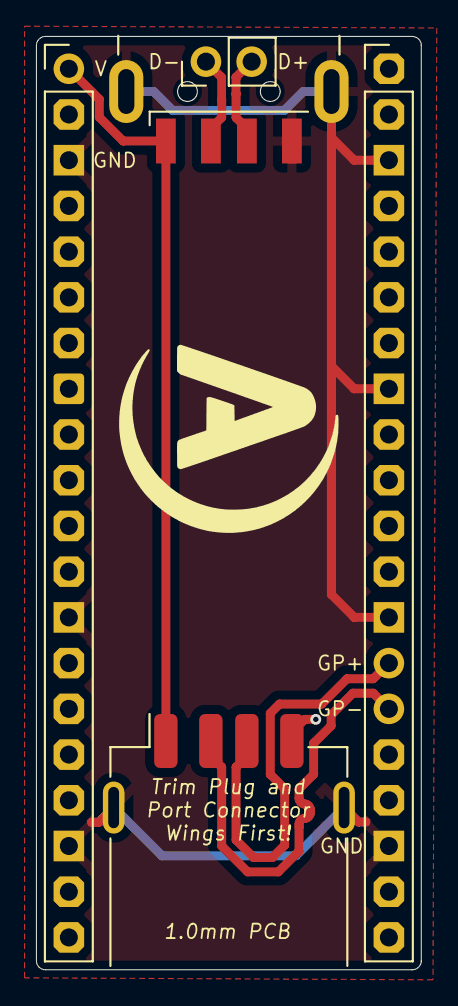
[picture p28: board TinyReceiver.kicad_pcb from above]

Board: 2 copper layers, 21.4 x 51.8 mm, 5 parts (0 on the bottom side), 6 nets.

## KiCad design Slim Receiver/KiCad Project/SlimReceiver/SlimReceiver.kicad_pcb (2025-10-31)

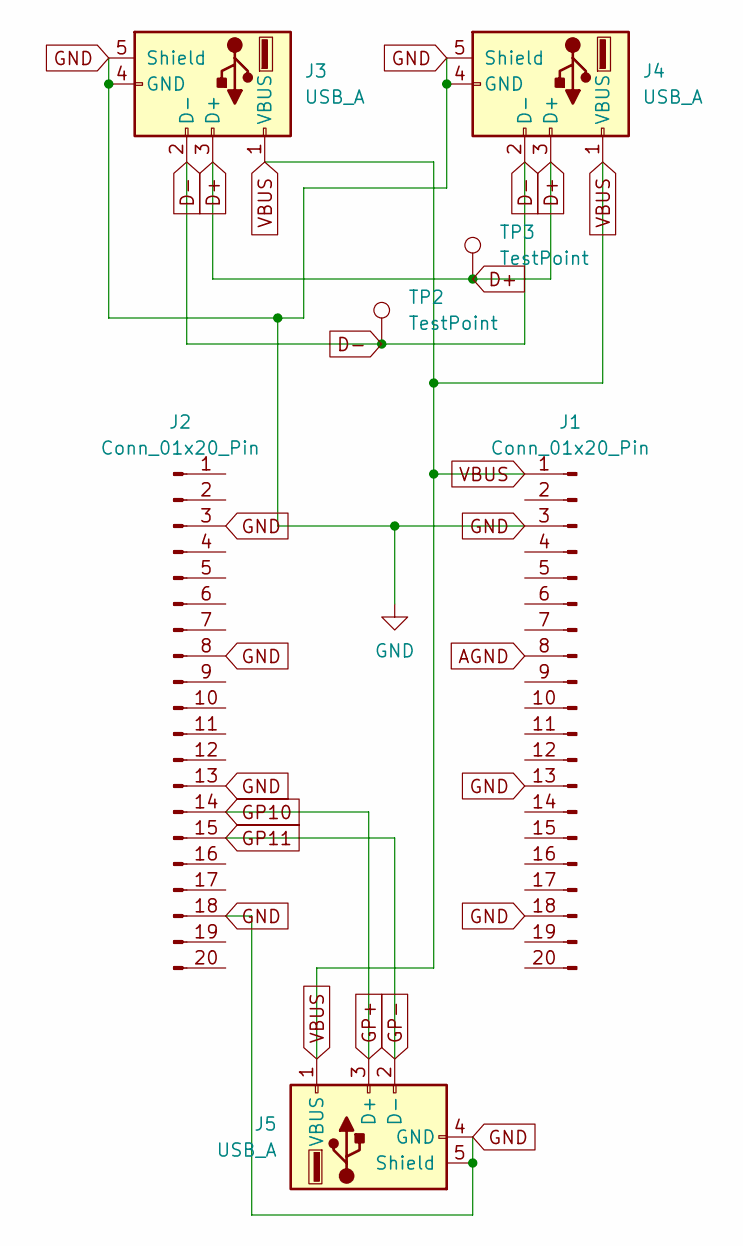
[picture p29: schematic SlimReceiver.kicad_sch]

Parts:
J1, J2: Conn_01x20_Pin; PinHeader_1x20_P2.54mm_Vertical_Low_Profile
J3: USB_A; USB_A_CNCTech_1001-011-01101_Horizontal_NoModel
J4: USB_A; USB_A_CNCTech_1001-011-01101_Horizontal
J5: USB_A; USB_A_Receptacle_GCT_USB1046_Model
TP2, TP3: TestPoint; MM_0926-1-15-20-75-14-11-0

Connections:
AGND: J1.8
D+: J3.3 (D+), J4.3 (D+), TP3.1
D-: J3.2 (D-), J4.2 (D-), TP2.1
GND: J1.3, J1.13, J1.18, J2.3, J2.8, J2.13, J2.18, J3.4 (GND), J3.5 (Shield), J4.4 (GND), J4.5 (Shield), J5.4 (GND), J5.5 (Shield)
GP+: J2.14, J5.3 (D+)
GP-: J2.15, J5.2 (D-)
VBUS: J1.1, J3.1 (VBUS), J4.1 (VBUS), J5.1 (VBUS)

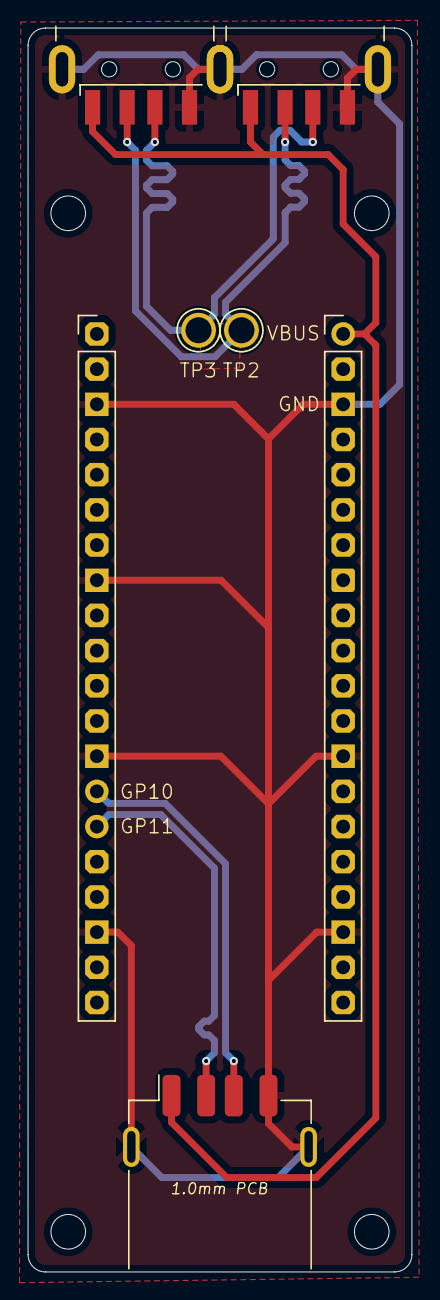
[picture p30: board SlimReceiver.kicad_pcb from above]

Board: 2 copper layers, 27.7 x 89.8 mm, 7 parts (0 on the bottom side), 6 nets.
